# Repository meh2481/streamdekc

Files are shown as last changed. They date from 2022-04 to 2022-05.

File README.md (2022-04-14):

# streamdekc
Like a streamdeck, but homemade and worse!

# Materials
Parts used:
- 8x [I2C OLED Displays](https://smile.amazon.com/dp/B09C5K91H7)
- 8x [Tactile push buttons](https://www.ebay.com/itm/303314070463)
- 4x [10K slide pots](https://smile.amazon.com/dp/B08C7C4PL3)
- 1x [QT Py 2040](https://www.adafruit.com/product/4900)
- 2x [74HC4051P Mux/Demux](https://smile.amazon.com/dp/B016G4MQH8)

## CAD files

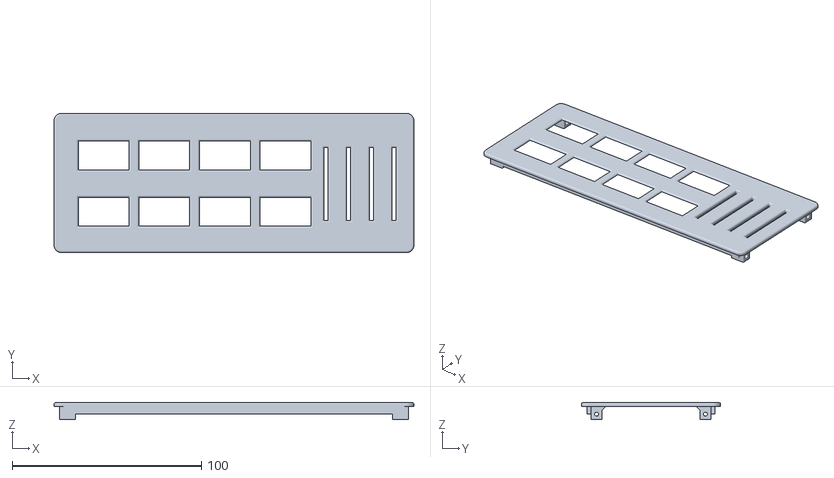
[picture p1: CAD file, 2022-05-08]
case/streamdekc-Lid.stl
190.0 x 73.5 x 9.00

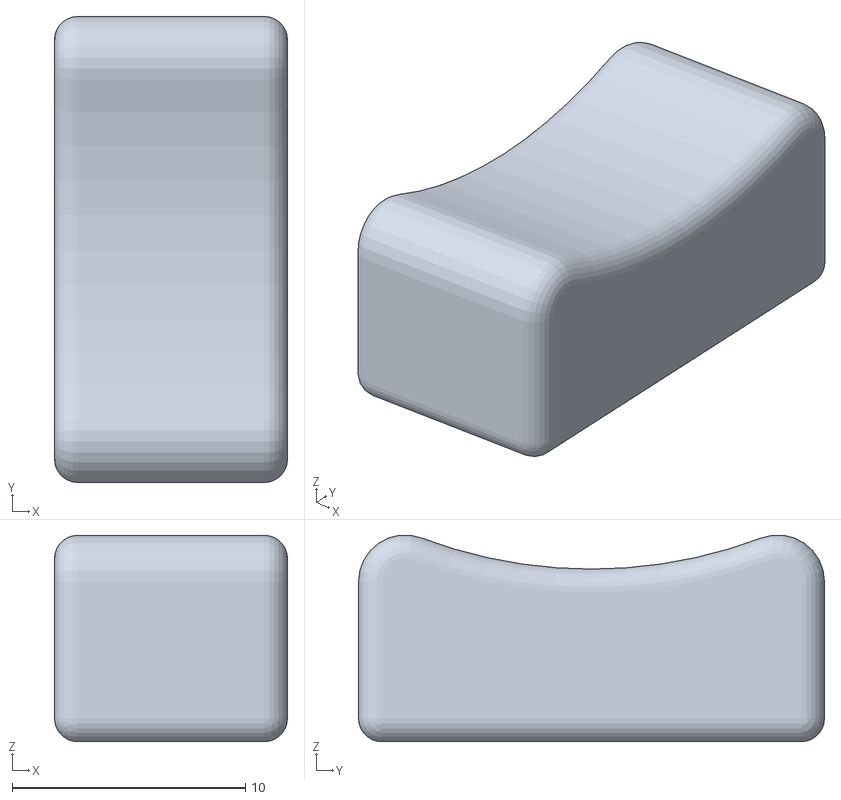
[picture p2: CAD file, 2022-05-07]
case/streamdekc-Slider.stl
10.0 x 20.0 x 8.86

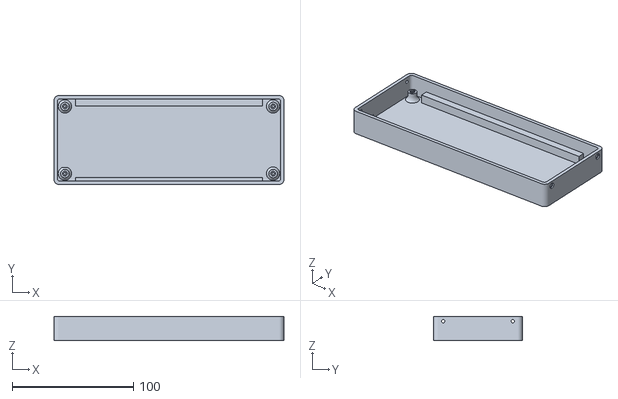
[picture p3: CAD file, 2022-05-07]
case/streamdekc-Base.stl
190.0 x 73.5 x 20.0

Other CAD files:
case/streamdekc.FCStd

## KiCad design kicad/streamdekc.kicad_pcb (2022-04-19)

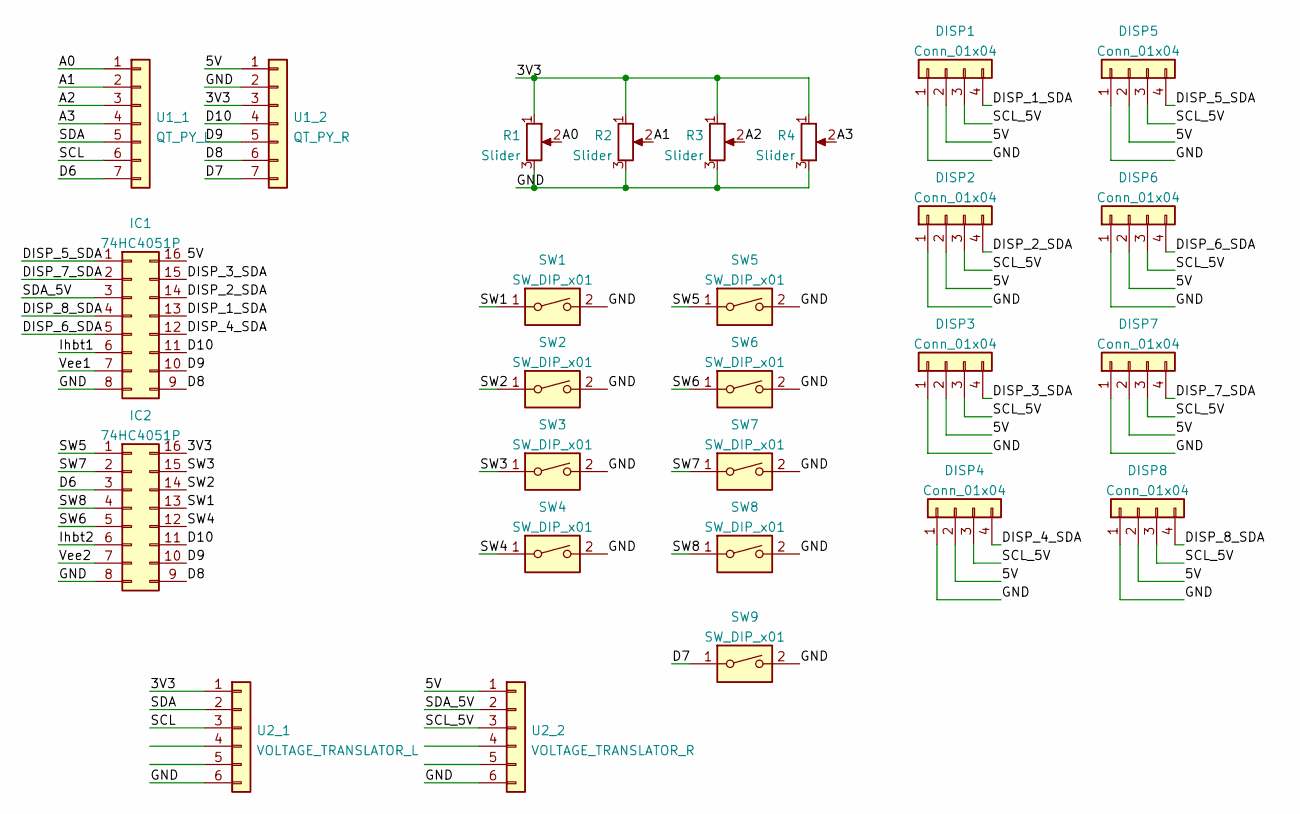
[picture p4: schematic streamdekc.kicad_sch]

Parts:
DISP1, DISP2, DISP3, DISP4, DISP5, DISP6, DISP7, DISP8: Conn_01x04; PinHeader_1x04_P2.54mm_Vertical
IC1, IC2: 74HC4051P; DIP-16_W7.62mm_LongPads
R1, R2, R3, R4: Slider; Potentiometer_Bourns_PTA3043_Single_Slide
SW1, SW2, SW3, SW4, SW5, SW6, SW7, SW8: SW_DIP_x01; Switch_2pin_6mm_p4.5mm
SW9: SW_DIP_x01; PinHeader_1x02_P2.54mm_Vertical
U1_1: QT_PY_L; PinHeader_1x07_P2.54mm_Vertical
U1_2: QT_PY_R; PinHeader_1x07_P2.54mm_Vertical
U2_1: VOLTAGE_TRANSLATOR_L; PinHeader_1x06_P2.54mm_Vertical
U2_2: VOLTAGE_TRANSLATOR_R; PinHeader_1x06_P2.54mm_Vertical

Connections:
/3V3: IC2.16, R1.1, R2.1, R3.1, R4.1, U1_2.3, U2_1.1
/5V: DISP1.2, DISP2.2, DISP3.2, DISP4.2, DISP5.2, DISP6.2, DISP7.2, DISP8.2, IC1.16, U1_2.1, U2_2.1
/A0: R1.2, U1_1.1
/A1: R2.2, U1_1.2
/A2: R3.2, U1_1.3
/A3: R4.2, U1_1.4
/D6: IC2.3, U1_1.7
/D7: SW9.1, U1_2.7
/D8: IC1.9, IC2.9, U1_2.6
/D9: IC1.10, IC2.10, U1_2.5
/D10: IC1.11, IC2.11, U1_2.4
/DISP_1_SDA: DISP1.4, IC1.13
/DISP_2_SDA: DISP2.4, IC1.14
/DISP_3_SDA: DISP3.4, IC1.15
/DISP_4_SDA: DISP4.4, IC1.12
/DISP_5_SDA: DISP5.4, IC1.1
/DISP_6_SDA: DISP6.4, IC1.5
/DISP_7_SDA: DISP7.4, IC1.2
/DISP_8_SDA: DISP8.4, IC1.4
/GND: DISP1.1, DISP2.1, DISP3.1, DISP4.1, DISP5.1, DISP6.1, DISP7.1, DISP8.1, IC1.8, IC2.8, R1.3, R2.3, R3.3, R4.3, SW1.2, SW2.2, SW3.2, SW4.2, SW5.2, SW6.2, SW7.2, SW8.2, SW9.2, U1_2.2, U2_1.6, U2_2.6
/Ihbt1: IC1.6
/Ihbt2: IC2.6
/SCL: U1_1.6, U2_1.3
/SCL_5V: DISP1.3, DISP2.3, DISP3.3, DISP4.3, DISP5.3, DISP6.3, DISP7.3, DISP8.3, U2_2.3
/SDA: U1_1.5, U2_1.2
/SDA_5V: IC1.3, U2_2.2
/SW1: IC2.13, SW1.1
/SW2: IC2.14, SW2.1
/SW3: IC2.15, SW3.1
/SW4: IC2.12, SW4.1
/SW5: IC2.1, SW5.1
/SW6: IC2.5, SW6.1
/SW7: IC2.2, SW7.1
/SW8: IC2.4, SW8.1
/Vee1: IC1.7
/Vee2: IC2.7

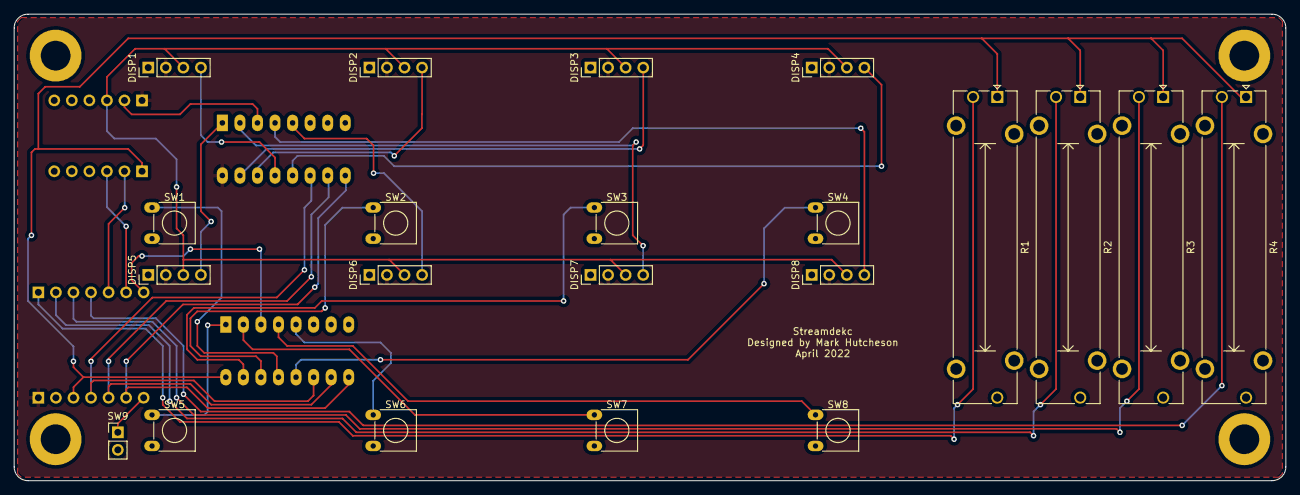
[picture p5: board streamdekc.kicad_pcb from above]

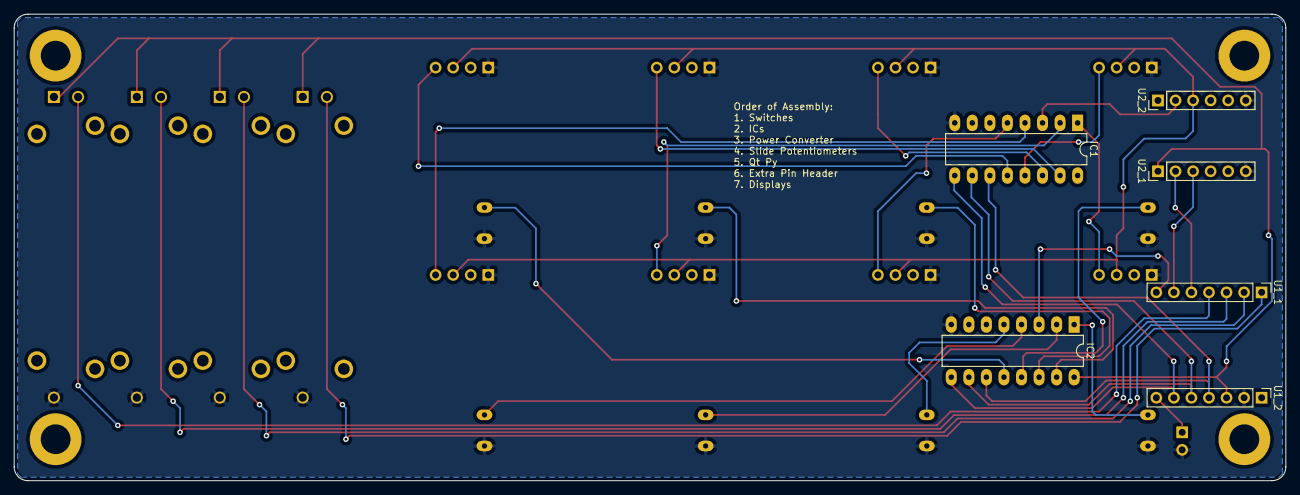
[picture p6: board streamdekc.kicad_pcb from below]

Board: 2 copper layers, 184.0 x 67.5 mm, 27 parts (6 on the bottom side), 32 nets.

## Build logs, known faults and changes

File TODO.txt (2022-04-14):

Test if 3.3V is logic high for a 5V circuit
Attach 3.3V <-> 5V i2c converter
Get sliding pots for analog input
Reuse i2c selection pins for button selection also
Find way to use 1 extra digital I/O pin

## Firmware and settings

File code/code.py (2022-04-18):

# Hardware: Adafruit Qt Py 2040
import adafruit_displayio_ssd1306
import displayio
from adafruit_display_text import label
import terminalio
import board
import time
from digitalio import DigitalInOut, Direction, Pull
from analogio import AnalogIn

# Init analog pins
analog_in = [AnalogIn(board.A0), AnalogIn(board.A1), AnalogIn(board.A2), AnalogIn(board.A3)]

# Init demuxer
A = board.D10
B = board.D9
C = board.D8

pin_a = DigitalInOut(A)
pin_a.direction = Direction.OUTPUT
pin_b = DigitalInOut(B)
pin_b.direction = Direction.OUTPUT
pin_c = DigitalInOut(C)
pin_c.direction = Direction.OUTPUT

pin_a.value = False
pin_b.value = False
pin_c.value = False

time.sleep(0.025)
displayio.release_displays()    # Normally this is done first, but the terminal out breaks the display if we don't mux select first.

# Init display
WIDTH = 128
HEIGHT = 64
BORDER = 2
i2c = board.I2C()

# Init first display
display_bus = displayio.I2CDisplay(i2c, device_address=0x3c)
display = adafruit_displayio_ssd1306.SSD1306(display_bus, width=WIDTH, height=HEIGHT)
# Swap to second display
pin_a.value = True
time.sleep(0.025)
# Fakeout teardown of second display
displayio.release_displays()
# Init second display
display_bus = displayio.I2CDisplay(i2c, device_address=0x3c)
display = adafruit_displayio_ssd1306.SSD1306(display_bus, width=WIDTH, height=HEIGHT)
# Swap back to first display
pin_a.value = False
time.sleep(0.025)

# Make the display context
splash = displayio.Group()
display.show(splash)

# Draw black background
color_bitmap = displayio.Bitmap(WIDTH, HEIGHT, 1)
color_palette = displayio.Palette(1)
color_palette[0] = 0x0
bg_sprite = displayio.TileGrid(color_bitmap, pixel_shader=color_palette, x=0, y=0)
splash.append(bg_sprite)

# Label text
text1 = "First display 0"
text_area = label.Label(terminalio.FONT, text=text1, color=0xFFFFFF, x=8, y=8)
splash.append(text_area)
text2 = "SSD1306-1"
text_area2 = label.Label(
    terminalio.FONT, text=text2, scale=2, color=0xFFFFFF, x=9, y=44
)
splash.append(text_area2)

# Update the second display
time.sleep(0.025) # Wait for i2c calls to first display to finish
pin_a.value = True

# Fakeout a full display redraw by changing the x location of the bg image
splash.x = 1
splash.x = 0
text_area2.text = "SSD1306-2"
text_area.text = "Second display 0"

# Init pin for button I/O
button_pin = board.D6
button = DigitalInOut(button_pin)
button.direction = Direction.INPUT
button.pull = Pull.UP

times_pressed_display_1 = 0
times_pressed_display_2 = 0
pressed_button_1 = False
pressed_button_2 = False

# Spin for a bit to give displays time to settle before swapping back and forth. idk why this is needed but the displays bork without it.
start_time = time.monotonic()
while True:
    if time.monotonic() - start_time > 0.5:
        break

analog_vals_smoothed = [
    [0 for i in range(5)] for j in range(4)
]

# Main loop
while True:
    # Swap to button/display 1
    pin_a.value = False
    time.sleep(0.025)
    if not button.value:
        if not pressed_button_1:
            times_pressed_display_1 += 1
            # print(f'Times pressed button 1: {times_pressed_display_1}')
            pressed_button_1 = True
            text_area.text = f'First display {times_pressed_display_1}'
            time.sleep(0.025)
    else:
        pressed_button_1 = False

    # Swap to button/display 2
    pin_a.value = True
    time.sleep(0.025)
    if not button.value:
        if not pressed_button_2:
            times_pressed_display_2 += 1
            # print(f'Times pressed button 2: {times_pressed_display_2}')
            pressed_button_2 = True
            text_area.text = f'Second display {times_pressed_display_2}'
            time.sleep(0.025)
    else:
        pressed_button_2 = False

    for i in range(4):
        analog_vals_smoothed[i].append(analog_in[i].value)
        analog_vals_smoothed[i].pop(0)
        avg_val = sum(analog_vals_smoothed[i]) / len(analog_vals_smoothed[i]) / 65535
        if i == 0:
            print(f'Analog value: {round(avg_val, 2)}')

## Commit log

2022-04-14 Add initial BOM
2022-04-14 Trying 5V logic, scanlines off on display 1
2022-04-14 Fix terminal out breaking display 1
    [code.py]
2022-04-18 Add KiCad files
    [streamdekc.kicad_pcb, streamdekc.kicad_sch]
2022-04-19 Initial pcb design
    [streamdekc.kicad_pcb, streamdekc.kicad_sch]
2022-04-19 Move QtPy for easier (aka physically possible) assembly
    [streamdekc.kicad_pcb]
2022-04-19 Update assembly instructions on B.Silkscreen
    [streamdekc.kicad_pcb, streamdekc.kicad_sch]
2022-04-19 Gen gerber files
    [streamdekc.kicad_pcb]
2022-05-07 Add FreeCAD and stl files
    [streamdekc-Base.stl, streamdekc-Lid.stl, streamdekc-Slider.stl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]
2022-05-07 Move folder to more proper name
    [streamdekc-Base.stl, streamdekc-Lid.stl, streamdekc-Slider.stl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]
2022-05-08 Giving up on this project for now; I2C hardware problems, case needs redesign
    [streamdekc-Lid.stl, streamdekc.FCStd]
